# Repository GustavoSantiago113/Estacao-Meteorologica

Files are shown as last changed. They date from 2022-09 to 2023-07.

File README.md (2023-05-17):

# Weather Station

## List of Contents

1. [Objective](#objective)
2. [Weather Station working flow](#weather-station-working-flow)
3. [List of Materials](#list-of-materials)
4. [Circuit Board](#circuit-board)
5. [Algorithm](#algorithm)
6. [3D Files](#3d-files)
7. [Structure](#structure)
8. [Future works](#future-works)

---

## Objective
Develop a weather station to collect air temperature and humidity, luminosity, wind speed and precipitation in field using Arduino and sensors. It is energized with a solar panel and batteries. All data is saved in a microSD card along with the date and time.

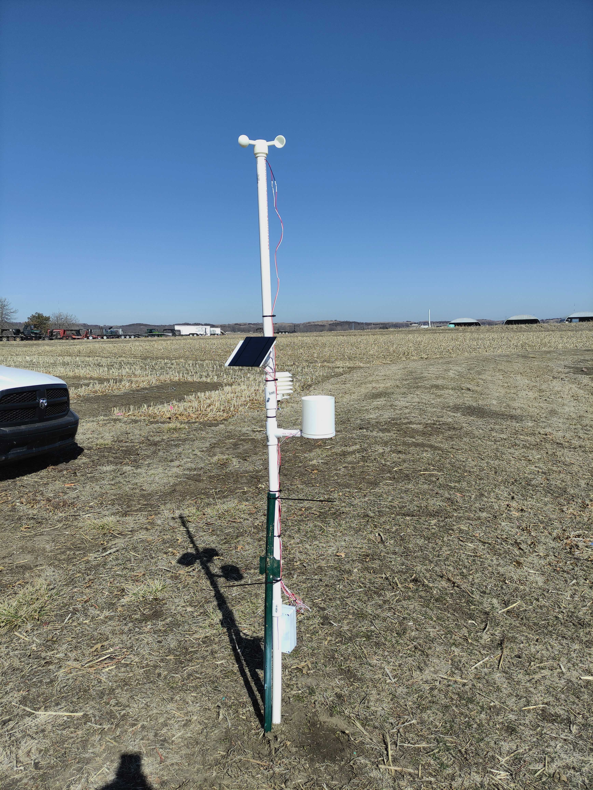
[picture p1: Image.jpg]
Weather Station build


---

## Weather Station working flow
Into a loop that repeats every 1 minute, the sensors get the data values and store into a .txt file. The .txt file is in the microSD card. Along with the sensors' reading data, the date and time is also sent to the .txt file.

The final .txt file is a line per reading with date, hour and sensors' data, all separated by commas.

---

## List of Materials

| Belongs to | Material | Amount |
|--- | --- | --- |
| Main Board | Arduino Uno | 1 |
| Main Board | microSD card module | 1 |
| Main Board | 32 GB microSD card | 1 |
| Main Board | RTC module DS3231 + battery | 1 |
| Main Board | Wires for connections | X |
| Main Board | Arduino enclosure | 1 |
| Rain Sensor | 3D structures in ABS | X |
| Rain Sensor | Rod of 3mm diameter and 30mm length (steel, aluminium...) possibly a little filed down to reduce to 2.95mm | 1 |
| Rain Sensor | Reed switch 1.8x7mm | 1 |
| Rain Sensor | 1k Ohm resistor | 1 |
| Rain Sensor | Round neodymium magnet 4x2mm | 1 |
| Rain Sensor | Bolts M3x6mm | 2 |
| Rain Sensor | Bolts or screws to fix the base on your support | 4 |
| Rain Sensor | Wires to connect to the reed switch | X |
| Rain Sensor | Glue to fix the magnet | A drop |
| Temperature & Humidity Sensor | AHT10 Sensor | 1 |
| Temperature & Humidity Sensor | 3D structures in ABS | X | 
| Temperature & Humidity Sensor | Bolts 10.5x0.5 cm and sow | 3 |
| Temperature & Humidity Sensor | Bolt to fix the sensor in place | 1 |
| Temperature & Humidity Sensor | Wires | X |
| Wind Sensor | Reed Switch 2x14mm | 1 |
| Wind Sensor | 1k Ohm resistor | 1 |
| Wind Sensor | Wires | X |
| Wind Sensor | 3D structures in ABS | X |
| Wind Sensor | Sealed bearing, 5 mm ID, 8mm OD, 2.5mm thick | 1 |
| Wind Sensor | Rod for the bearings 5mm OD | 1 |
| Wind Sensor | 1k ohm resistor | 1 |
| Structure | PVC pipe | 235cm x 4.83cm diameter |
| Structure | PVC pipe | 20cm x 3.34cm diameter |
| Structure | PVC pipe | 10cm x 2.66cm diameter |
| Structure | T junction / Reduction of 4.83cm to 3.34cm diameter | 2 |
| Structure | T junction / Reduction of 4.83cm to 2.66cm diameter | 1 |
| Energy | Charger Module | 1 |
| Energy | Diode 1n4007 | 1 |
| Energy | Panel with minimum 4Wp, 0.48A and 9V | 1 |
| Energy | Rechargeable battery of 0.3 Ah and 9V | 1 |
| Energy | Wires | X |
| Light Sensor | LDR 5mm | 1 |
| Light Sensor | 1k Ohm resistor | 1 |
| Light Sensor | Wires | X |

<br>

---

## Circuit Board
A circuit board were made to make everything more organized and avoid wrong connections and wires out of place. The .dxf file containing the circuit board's draw is in the folder Circuit_Board.

---

## Algorithm
The algorithm was made in C++ using Arduino IDE, since it is for Arduino. It is located in the Algorithm/Programa_o folder. The algorithm is structured as followed:
- Inclusion of libraries for SD card, RTC clock, temperature and humidity sensor;
- Declaration of variables for each sensor and module;
- Setup, that only runs once when the Arduino is restarted. On this function, i) the pin for the Pluviomether and Anemomether reed switchs' are declared; ii) initialize the microSD card; iii) the clock is initialized and adjusted only once; iV) the temperature and humidity sensor is initialized;
- Loop, that keep running. On this function, i) The super delay function is inserted to work every 5 minutes, ii) the Anemomether data (wind speed) is collected and adjusted, iii) the luminosity data is collected and adjusted, iv) temperature and humidity data is collected, v) the Pluviomether data is collected (rain) and adjusted, vi) Date and Time variables are collected and stored, vii) the .txt file in the microSD card is opened and all variables are stored into it, closing the .txt after that;
- Super delay function. It is created to take readings of rain and wind at everytime and just after a time, saves the data in the microSD card. To count the rain and wind, it verifies the state of the reed switch, and if it was changed, it is counted and the value changes.

---

## 3D Files
The main 3D files were all gotten at Thingiverse website, having different authors. The support 3D files were designed by the author in Fusion360 software.
### Anemomether
There are structures siliar to spoons that "collect" the wind, moving the axis attached to it. In the moving structure, there is a magnet that moves in the same speed as the spoons. A stopped structure holds the reed switch which captures the magnet movement and records how many times it passed through.

### Pluviomether
A funnel recalls the rain and send it directly to a bending tool that, when full, bends and throw the water away. As it bends, the magnet attached to it makes the reed switch records the movement and store how many time it bended (amount of rain).

### Temperature and humidity sensor protector
Just a structure to protect the sensor against the rain, wind and other environmental issues, in an attempt to reduce errors for the readings

---

## Structure
A PVC structure were built and stucked 50cm in the ground. As the image below shows, three Ts in 120 degrees between them are in the pipe to attach the sensor and solar panel structures'.
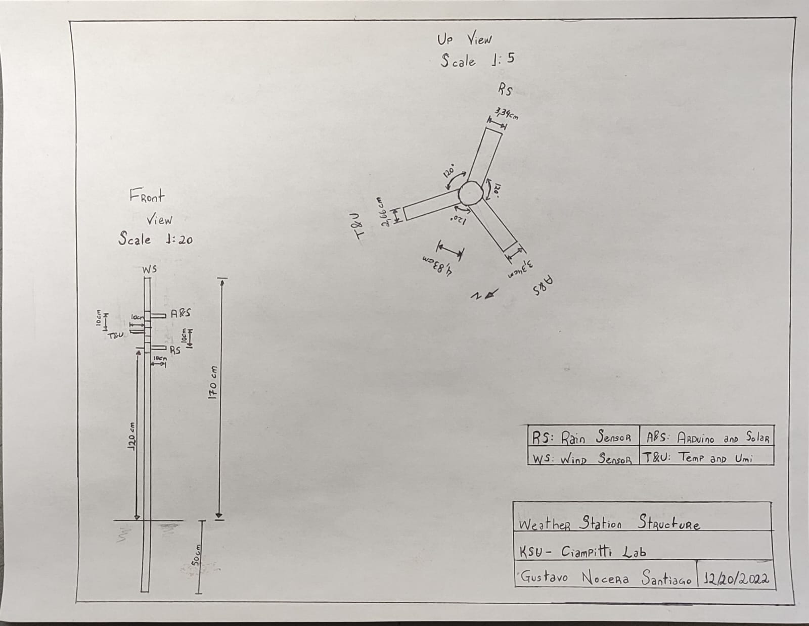
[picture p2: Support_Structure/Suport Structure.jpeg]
Structure


---

## Future works

The future work is to connect the weather station to the internet and upload the data to the cloud. Being the data in an online database, there is no need of removing and reading the microSD card. Also, spread weather stations over Kansas to obtain real time weather data of all the state. And lastly, Connect the database to a web application.

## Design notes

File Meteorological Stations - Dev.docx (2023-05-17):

Development of Meteorological Stations

Idea: Building stations to measure the most important agronomical variables and save information

Number of Stations: X

Variables required to measure: Temperature, Atmospheric pressure, wind speed, air humidity, luminosity, precipitation.

Places where will be the stations

- North Farm

Working alternatives:

- Batteries and Solar Pannel
- Electrical line using a 12/3.5 v charger
- Modern approach as shown in article: “Hybridized energy harvesting device based on high-performance triboelectric nanogenerator for smart agriculture applications"

Boards Alternatives

- Arduino UNO
- Arduino Nano
- NodeMCU
- Look at some boards with bluetooth/wifi

Structures

- 3D printed (Sensors and boards protections’);
- Commercial ones;
- Build in places that works with metal (Sustentation)

Inventory

- Arduino boards: 5
- Temperature/Humidity sensor: 1
- Pressure sensor: 0
- Batteries
- 2x 3.7V and 2000mAh
- 1x 3.7V and ? mAh
- 6x 1.2V and 1300mAh
- 1x 11.1 V
- 7x Batteries holders
- Solar Pannels: 5
- Cables
- 3x Arduino UNO – USB
- 29x Female-male pin
- 29x Female-male protected gathered in 3
- 29x Male protected-non protected gathered in 2
- 27x Female protected-male non protected gathered in 2
- 12x 9V battery clips
- Regulator charge: 16
- Arduino Clocks: 1
- Clock: 0
- Soil moisture sensors*: 1
- Air humidity sensor: 0
- Luminosity sensor
- 2x TSL2561
- 39 LDR
- Magnetic sensor (Reed Switch): 19
- Resistors: 25 of (470, 270, 33, 1k, 100k, 2.2k, 3.3k, 10k, 330, 100, 68, 150, 2k, 4.7k, 220 Ohm)
- Capacitor 100uF: 10
- Diodo IN4007: 50
- 1 Small protoboard
- 2 micro SD shield with 8GB microSD
- 1 SD shield without SD Card
- Water level sensor: 2
- Rain sensor: 2
- 3 Packs of heat shrink

References

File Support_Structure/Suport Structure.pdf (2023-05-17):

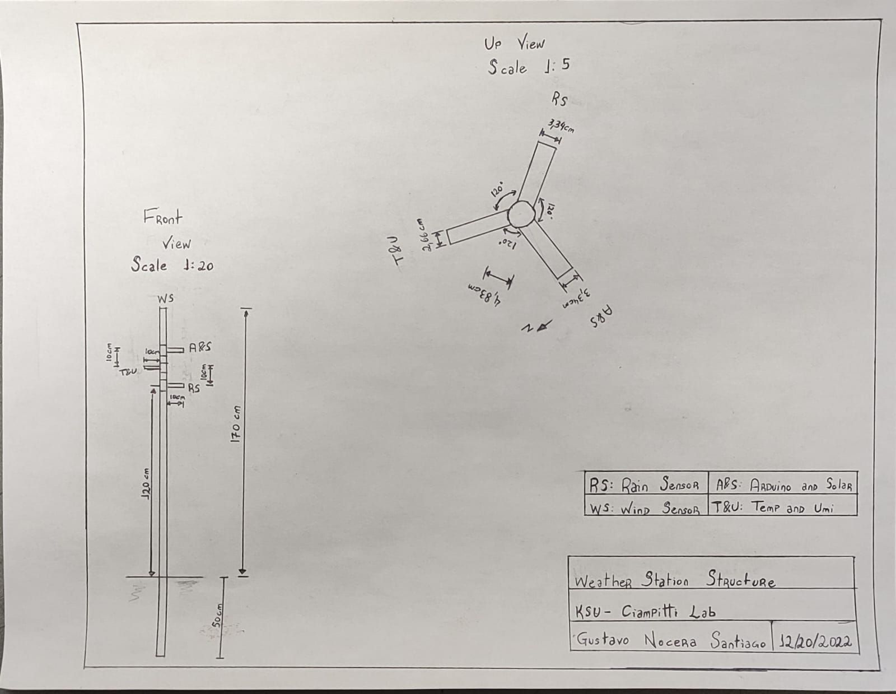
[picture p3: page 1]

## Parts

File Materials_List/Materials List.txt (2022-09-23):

1x AHT10;

2x Sensor magnético Reed Switch;

2x Resistor 1kΩ;

1x LDR 5 mm;

1x Resistor 10kΩ;

1x RTC DS3231 com bateria;

1X LCD1602 + I2C (LCM1602);

1X Módulo SD Card;

1x Arduino Nano;

1x Cartão SD;

1x Diodo 1n4007;

1x Capacitor de 100μF e 16 V;

1x Clip de bateria 9V;

1x Indicador de carga de bateria;

1x Bateria recarregável de 9 V e 450 mAh (mínimo);

1x Painel solar de 12 Wp (mínimo), 9 V e 2A ou 2x Painéis solares de 12Wp(mínimo), 9 V e 1A.

Cabos jumper macho-macho e macho-fêmea;

2x Ímãs pequenos;

Estrutura de suporte;

Placa de circuito;

Estruturas 3D (com rolamento e eixo para o anemômetro);

Cabo para passar a ligação ao Arduino;

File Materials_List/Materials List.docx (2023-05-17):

Main Board

1x Arduino Uno

1x SD card board for Arduino Uno + 32 GB SD card

Wires for connections

1x Clock module DS3231 + battery

1x Arduino enclosure

Rain Sensor

1x Rod of 3mm diameter and 30mm length (steel, aluminium...) possibly a little filed down to reduce to 2.95mm.

1x Reed switch 1.8x7mm

1x Round neodymium magnet 4x2mm

2x Bolts M3x6mm

4x Bolts or screws to fix the base on your support.

Wires, connector as you like to connect to the reed switch.

A drop of glue to fix the magnet.

3D structures printed in ABS

1x 1k ohm resistor

Temperature and Humidity Sensor

1x AHT10 Sensor

3D structures printed in ABS

3x Bolts 10.5x0.5 cm and sow

1x Bolt to fix the sensor in place

Wires

Wind Sensor

1x Reed Switch 2x14mm

Wires

3D structures printed in ABS

1x Sealed bearing, 5 mm ID, 8mm OD, 2.5mm thick

1x Rod for the bearings 5mm OD

1x 1k ohm resistor

Structure

235cm x 4.83cm diameter PVC pipe

3x T junction of 4.83cm diameter

2x reduction from 4.83cm to 3.34cm diameter

1x reduction from 4.83cm to 2.66cm diameter

20cm x 3.34cm diameter PVC pipe

10cm x 2.66cm diameter PVC pipe

Energy

1x Capacitor of 100uF and 16V

1x Diode 1n4007

1x Panel having minimum of 4 Wp and 0.48 and 9V

1x Rechargeable battery of 9.2 Ah and 9V (If use on winter)

1x Rechargeable battery of 8.2 Ah and 9V (If not using on winter)

Wires

Light

1x LDR 5mm

1x 1k ohm resistor

Wires

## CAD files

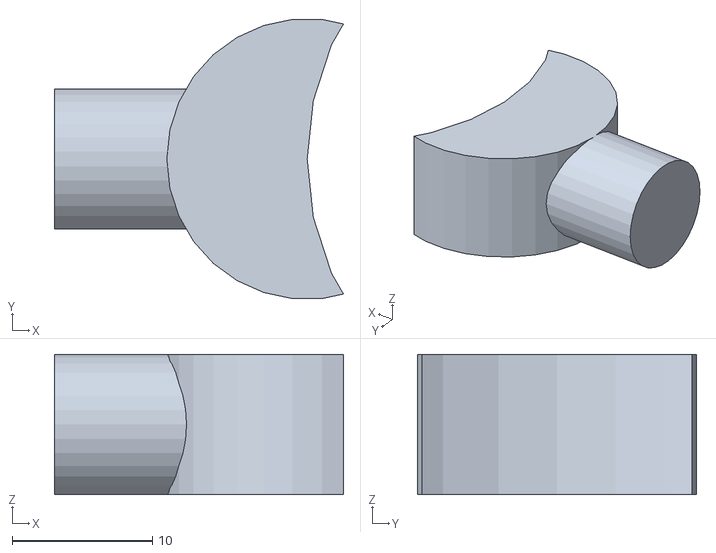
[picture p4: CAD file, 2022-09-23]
3D_Structure/Anemômetro/04Anem_bracket.stl
20.6 x 19.9 x 10.0

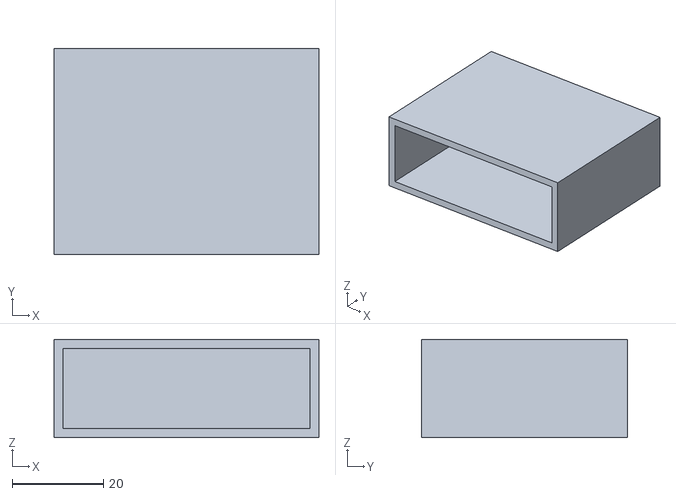
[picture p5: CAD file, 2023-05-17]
3D_Structure/Battery Holder.stl
58.0 x 45.0 x 21.5

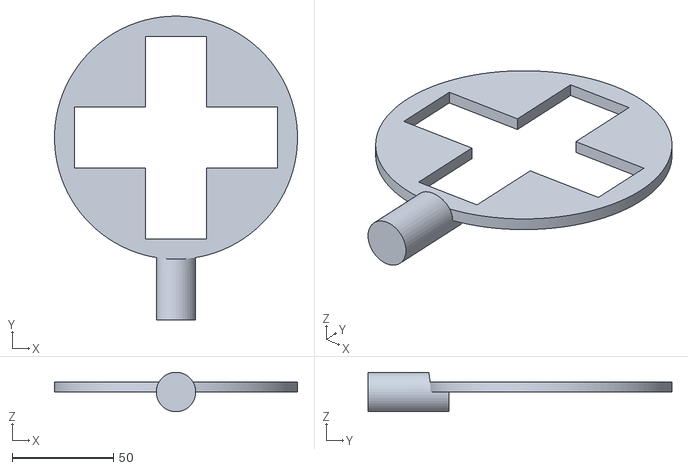
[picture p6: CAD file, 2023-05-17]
3D_Structure/Pluviômetro/Attachment to support.stl
120.0 x 150.0 x 19.5

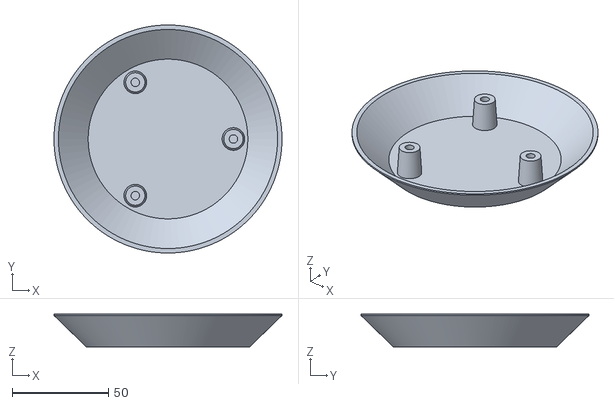
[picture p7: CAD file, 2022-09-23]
3D_Structure/Protetor temp e umi/Rad_Shd_Top_V1.stl
118.5 x 118.5 x 17.0

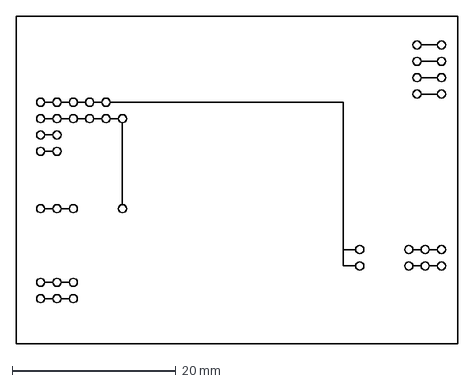
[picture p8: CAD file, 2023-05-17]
Circuit_Board/Circuit_Board.dxf
54.0 x 40.0 mm

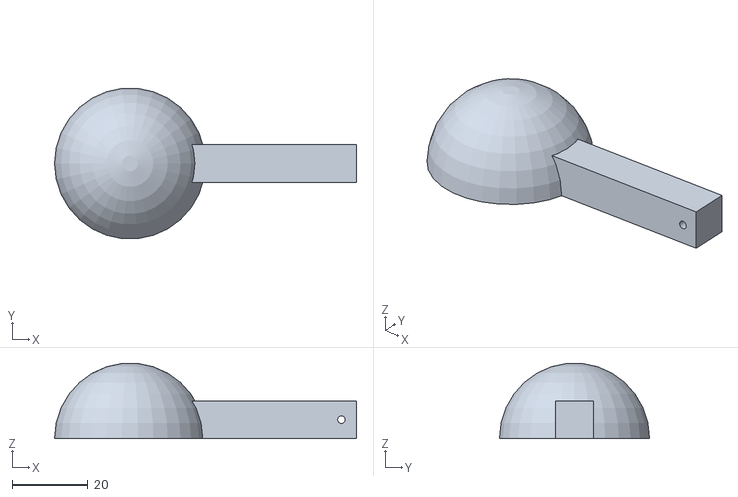
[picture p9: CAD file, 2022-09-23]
3D_Structure/Anemômetro/01Anem_Cup.stl
80.0 x 39.8 x 19.9

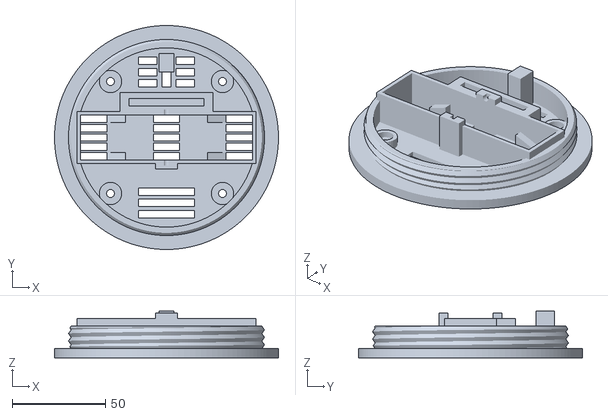
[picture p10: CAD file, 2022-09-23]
3D_Structure/Pluviômetro/Base.stl
120.0 x 120.0 x 25.0

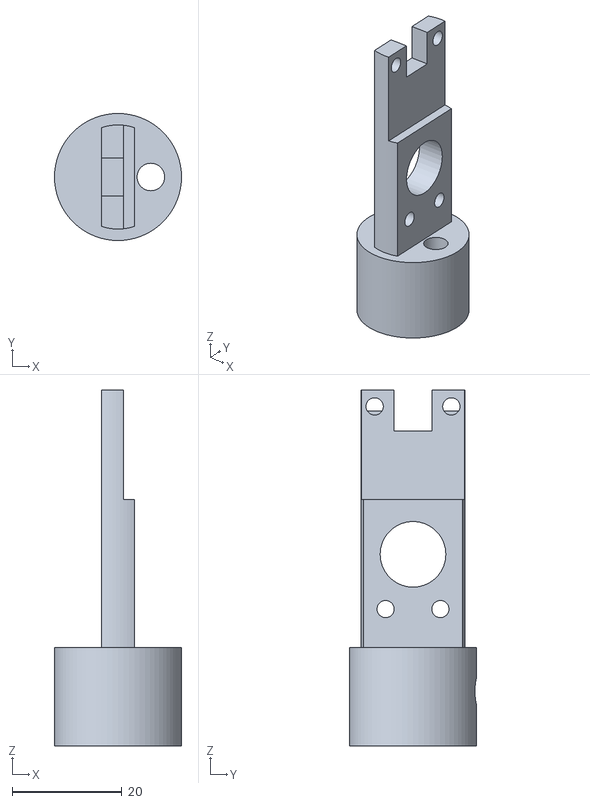
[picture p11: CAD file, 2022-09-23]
3D_Structure/Protetor temp e umi/SHT15_mount_V1.stl
23.2 x 23.2 x 65.0

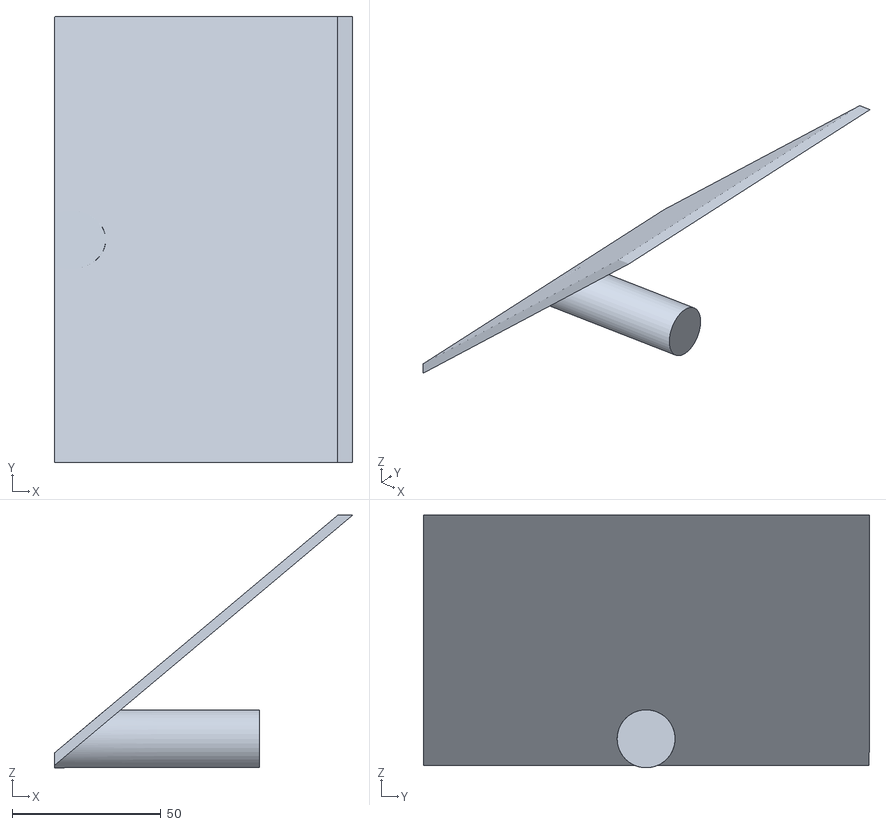
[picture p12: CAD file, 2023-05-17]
3D_Structure/Solar.stl
100.4 x 150.1 x 85.0

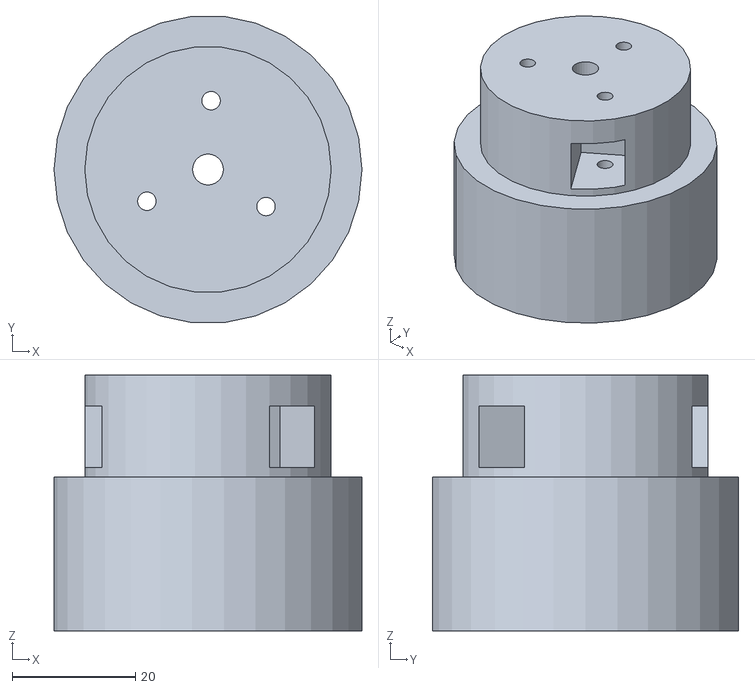
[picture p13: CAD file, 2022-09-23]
3D_Structure/Anemômetro/02Anem_center.stl
50.0 x 49.7 x 41.5

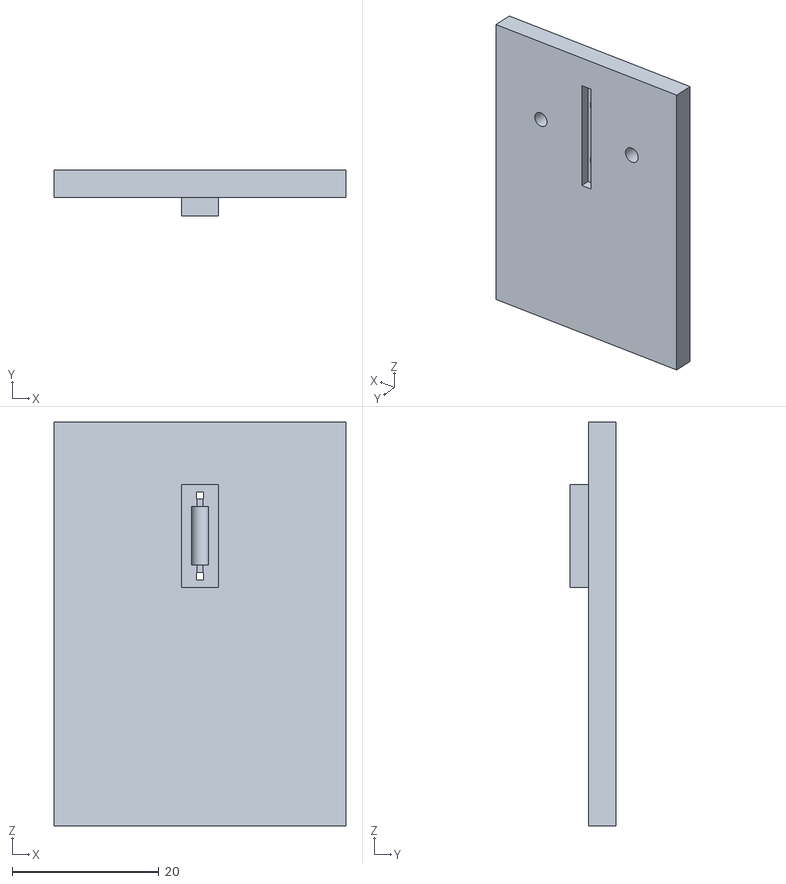
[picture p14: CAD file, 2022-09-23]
3D_Structure/Pluviômetro/Sensor.stl
39.8 x 6.25 x 55.0

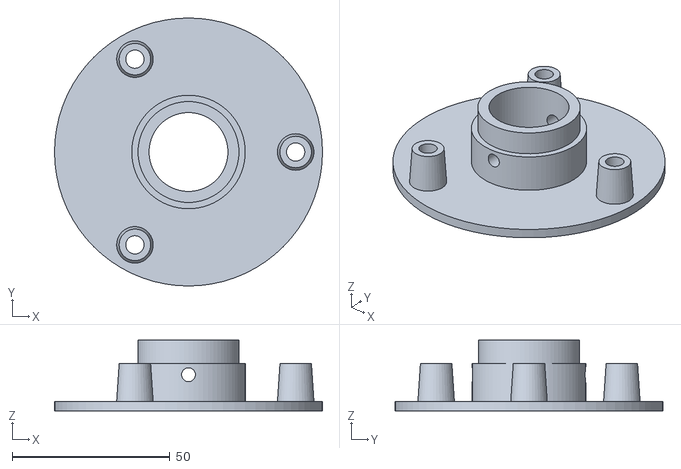
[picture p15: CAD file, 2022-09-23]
3D_Structure/Protetor temp e umi/Rad_Shd_Base_V1.stl
85.0 x 85.0 x 22.5

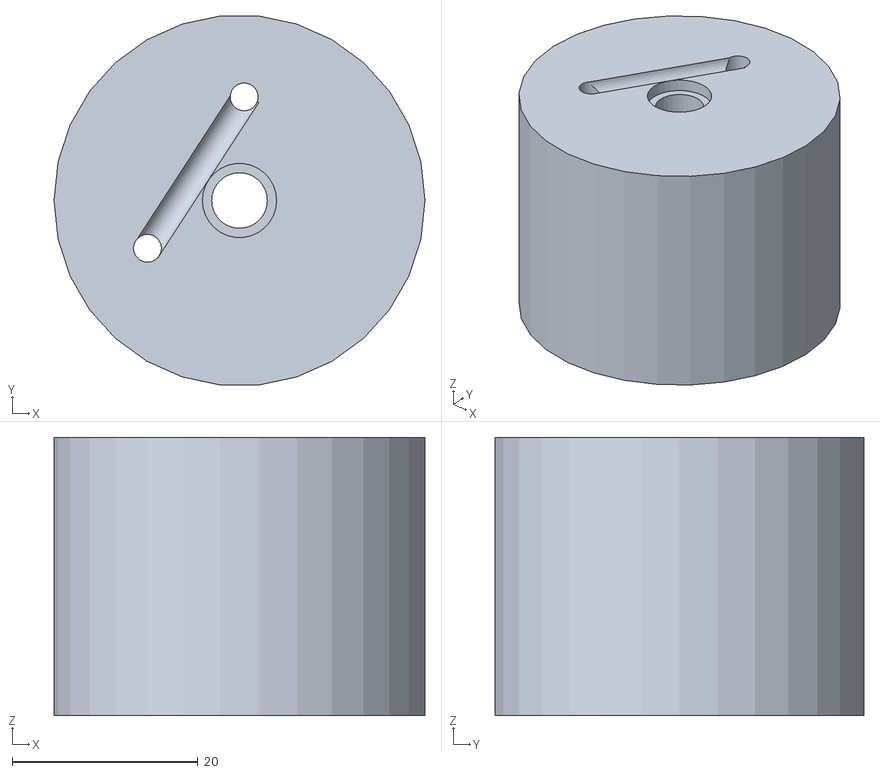
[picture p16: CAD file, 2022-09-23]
3D_Structure/Anemômetro/03Anem_Base.stl
40.0 x 39.8 x 30.0

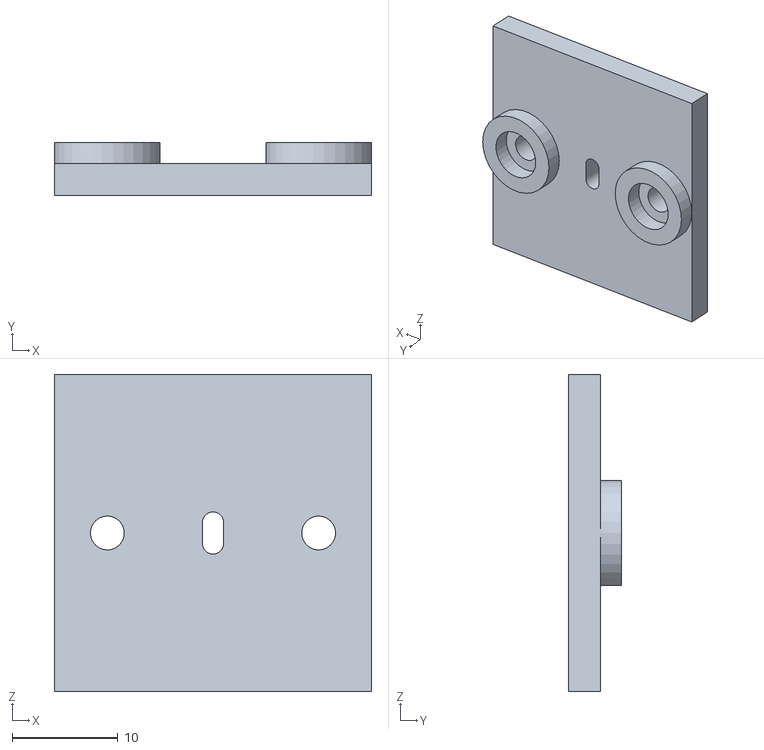
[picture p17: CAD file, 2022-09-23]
3D_Structure/Pluviômetro/Sensor_back.stl
30.0 x 5.00 x 30.0

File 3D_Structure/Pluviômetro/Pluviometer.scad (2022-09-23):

include <polyScrewThread_r1.scad>

full = true;
fnval = 120;



module cylinder_nut(df,hg,sth,clf,cod,crs){  
  hex_countersink_ends(sth/2,cod,clf,crs,hg);
  screw_thread(cod,sth,clf,hg,crs,-2);
}

module triangleR(a, b, h, c){
  linear_extrude(height = h, center = c, convexity = 10)
  resize([a, b])
  polygon([[0,0], [1,0], [0,1]], paths=[[0,1,2]]);
}

module triangleRa(a, angle, h, c){
  rotate([90, 0, 0])
  linear_extrude(height = h, center = c, convexity = 10)
  resize([a, a*tan(angle)])
  polygon([[0,0], [1,0], [0,1]], paths=[[0,1,2]]);
}

module triangleI(x, y, z, c){
  rotate([90, 0, 0])
  linear_extrude(height = y, center = c, convexity = 10)
  resize([x, z])
  polygon([[-1,0], [1,0], [0,1]], paths=[[0,1,2]]);
}


module bucket2(){
  difference(){
    union(){
      difference(){
        triangleI(70, 20, 25, true);
        
        translate([-70/4-1/2, 0, (25+2)/2]) cube([70/2, 20-4, 25-2], center = true);
        translate([70/4+1/2, 0, (25+2)/2]) cube([70/2, 20-4, 25-2], center = true);
      }
      
      triangleI(20, 20, 15, true);
    }
    
    translate([0, 0, 3]) rotate([90, 0, 0]) cylinder(d=3.25, h=20, center=true, $fn=30);
  }
  
  //magnet
  translate([0, 10+2/2, 21])
  rotate([90, 0, 0])
  difference(){
    cylinder(d=6.25, h=2, center=true, $fn=30);
    cylinder(d=4.25, h=2, center=true, $fn=30);
  }  
}

module bucket(){
  difference(){
    union(){
      difference(){
        triangleI(70, 20, 25, true);
        
        translate([-70/4-1/2, 0, (25+1)/2]) cube([70/2, 20-2, 25-1], center = true);
        translate([70/4+1/2, 0, (25+1)/2]) cube([70/2, 20-2, 25-1], center = true);
      }
      
      triangleI(25, 20, 15, true);
    }
    
    translate([0, 0, 3]) rotate([90, 0, 0]) cylinder(d=3.25, h=20, center=true, $fn=30);
  }
  
  //magnet
  translate([0, 10+2/2, 21])
  rotate([90, 0, 0])
  difference(){
    cylinder(d=6.25, h=2, center=true, $fn=30);
    cylinder(d=4.25, h=2, center=true, $fn=30);
  }  
}

module base(){
  translate([0, 0, -5/2])
  difference(){
    cylinder(d=120, h=5, center=true, $fn=fnval);
    
    //water holes
    for(dy = [-2:1:2], dx = [-1, 0, 1]){
      translate([-39*dx, 5*dy, 0]) cube([14, 4, 5], center = true);
    }  

    for(dy = [-1:1:1]){
      translate([0, 6*dy-35, 0]) cube([30, 4, 5], center = true);
    }    
    
    for(dy = [-1:1:1], dx = [-1, 1]){
      translate([10*dx, 6*dy+35, 0]) cube([10, 4, 5], center = true);
    }   
    
    //screw holes
    for(dx = [-1,1], dy = [-1, 1]){
      translate([30*dx, 30*dy, 0]) cylinder(d=4.25, h=5, center=true, $fn=30);
    }
    
    //cable hole
    translate([0, 31, 0]) cube([5, 8, 5], center = true);
  }
  
  //screw holes
  for(dx = [-1,1], dy = [-1, 1]){
    translate([30*dx, 30*dy, 0]) 
    difference(){
      cylinder(d=12, h=5, center=false, $fn=30);
      cylinder(d=4.25, h=5, center=false, $fn=30);
      translate([0, 0, 5-3]) cylinder(d=8, h=3, center=false, $fn=30);
    }
  }
  
  //cable holder
  translate([0, 31+8/2+10/2, 20/2]) cube([8, 10, 20], center = true);
  
  //border
  translate([0, 0, 16/2])
  difference(){
    cube([92+2*2, 24+2*2, 16], center = true);
    cube([92, 24, 16], center = true);
  }
   
  
  //holder
  difference(){
    translate([0, 0, 18/2+1/2]) cube([12, 20+2*2+2*5, 19], center = true);
    
    translate([0, 0, 18/2]) cube([12, 20+2*2, 20], center = true);
    translate([0, 0, 18]) rotate([90, 0, 0]) cylinder(d=3.25, h=20+2*2+2*3, center=true, $fn=30);
  }
  
  //stop
  difference(){
      for(dx = [-1, 1]) {
        translate([22*dx, 0, 3]) scale([dx, 1, 1]) {
          translate([10/2, 0, -3/2]) cube([10, 24, 3], center = true);
          triangleRa(10, 20, 24, true);
        }
      }
      translate([0, 0, 10/2]) cube([70, 20-2*2, 10], center = true);
  }
  
  //pcb holder  
  translate([0, 19, 16/2])
  difference(){
    cube([50, 10, 16], center = true);
    cube([40, 4, 16], center = true);
  }
  
  
  //thread  
  if(full){
    difference(){
      translate([0, 0, 0]) screw_thread(105, 4, 55, 12, PI/2, 2);
      cylinder(d=96, h=14, center=false, $fn=fnval);
    }
  }
  else{
    difference(){
      cylinder(d=105, h=14, center=false, $fn=fnval);
      cylinder(d=96, h=14, center=false, $fn=fnval);
    }
  }
    
  
}

module funnel(){
  
  difference(){
    union(){
      translate([0, 0, 120])
      mirror([0, 0, 1])
      rotate_extrude(angle = 360, convexity = 2, $fn=fnval)
      difference(){
        resize([10*sqrt(100/PI)+2, 70+2])  polygon([[0,0], [1,0], [0,1]], paths=[[0,1,2]]);
        resize([10*sqrt(100/PI), 70])  polygon([[0,0], [1,0], [0,1]], paths=[[0,1,2]]);
      }
            
      difference(){
        cylinder(r=10*sqrt(100/PI)+2, h=120, center=false, $fn=fnval);
        cylinder(r=10*sqrt(100/PI), h=120, center=false, $fn=fnval);
      }
      
      
      translate([0, 0, 120-70-10+2.5]) cylinder(d=7, h=10, center=false, $fn=30);
    }
    translate([0, 0, 120-70-10+2.5]) cylinder(d=5, h=10, center=false, $fn=30);
  }
  
  difference(){
    translate([0, 0, 14/2]) cylinder(r=10*sqrt(100/PI), h=14, center=true, $fn=fnval);
    if(full){
      cylinder_nut(100, 14, 4, 55, 105.5, 0.5);
    }
    else{
      translate([0, 0, 14/2]) cylinder(d=105.5, h=14, center=true, $fn=fnval);
    }
  }
  
  translate([0, 0, 14+5/2]) 
  difference(){
    cylinder(r=10*sqrt(100/PI), h=5, center=true, $fn=fnval);
    cylinder(r2=10*sqrt(100/PI), r1=105.5/2, h=5, center=true, $fn=fnval);
  }
  
  
}

module sensor(){
    difference(){
        union(){
            translate([0, -0.25/2, 0]) cube([40-0.25, 4-0.25, 55], center = true);
            
            translate([0, -3, 12])
            difference(){
                cube([5, 3, 14], center = true);
                translate([0, -3/2+2.25/2, 0]) cylinder(d=2.25, h=8, center=true, $fn=30);
                translate([0, -3/2+2.25/4, 0]) cube([2.25, 2.25/2, 8], center = true);
                translate([0, -3/2+2.25/4, 0]) cube([0.75, 2.25/2, 12], center = true);
            }
            
        }
                
        translate([0, -1, 12+6-0.5]) cube([1, 8, 1], center = true);
        translate([0, -1, 12-6+0.5]) cube([1, 8, 1], center = true);
        
        translate([0, 1.75/2, 12]) cube([2, 1.75, 20], center = true);
        
        for(dx = [-1, 1]) 
        translate([-10*dx, (3.75-3)/2, 12]) rotate([90, 0, 0]) cylinder(d=2.7, h=3, center=true, $fn=30);
     }
}

module sensor_back(){
    difference(){
        translate([0, 0, 0]) cube([30, 3, 30], center = true);
    
        for(dx = [-1, 1]) 
            translate([-10*dx, 0, 0]) rotate([90, 0, 0]) cylinder(d=3.2, h=5, center=true, $fn=30);

        hull(){
            translate([0, 0, 1]) rotate([90, 0, 0]) cylinder(d=2, h=5, center=true, $fn=30);
            translate([0, 0, -1]) rotate([90, 0, 0]) cylinder(d=2, h=5, center=true, $fn=30);
        }
    }
    
    for(dx = [-1, 1]) 
        translate([-10*dx, (3+2)/2, 0]) rotate([90, 0, 0])
            difference(){
               cylinder(d=10, h=2, center=true, $fn=30);
               cylinder(d=6, h=2, center=true, $fn=30);
            }
    
}

module bending_tool(){
    difference(){
        cube([11, 5, 5], center = true);
        translate([0, 0, 2]) cube([11, 1, 1], center = true);
        translate([0, 0, 2]) cube([8, 2, 2], center = true);
    }
}

module assembled(){
    translate([0, 0, -18])base();
    rotate([0, 0, 0]) translate([0, 0, -3]) bucket();
    translate([0, 19, 55/2-18]) sensor();
    translate([0, 24, 55/2-18+12]) sensor_back();
    translate([0, 0, -18]) funnel();
}

module exploded(){
    translate([0, 0, -18])base();
    rotate([0, 0, 0]) translate([0, 0, 20]) bucket();
    translate([0, 19, 30]) sensor();
    translate([0, 30, 42]) sensor_back();
    translate([0, 0, 70]) funnel();
}

//assembled();

exploded();

//bending_tool();

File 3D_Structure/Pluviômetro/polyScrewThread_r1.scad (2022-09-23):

/*
 *    polyScrewThread_r1.scad    by aubenc @ Thingiverse
 *
 * This script contains the library modules that can be used to generate
 * threaded rods, screws and nuts.
 *
 * http://www.thingiverse.com/thing:8796
 *
 * CC Public Domain
 */

module screw_thread(od,st,lf0,lt,rs,cs)
{
    or=od/2;
    ir=or-st/2*cos(lf0)/sin(lf0);
    pf=2*PI*or;
    sn=floor(pf/rs);
    lfxy=360/sn;
    ttn=round(lt/st+1);
    zt=st/sn;

    intersection()
    {
        if (cs >= -1)
        {
           thread_shape(cs,lt,or,ir,sn,st);
        }

        full_thread(ttn,st,sn,zt,lfxy,or,ir);
    }
}

module hex_nut(df,hg,sth,clf,cod,crs)
{

    difference()
    {
        hex_head(hg,df);

        hex_countersink_ends(sth/2,cod,clf,crs,hg);

        screw_thread(cod,sth,clf,hg,crs,-2);
    }
}


module hex_screw(od,st,lf0,lt,rs,cs,df,hg,ntl,ntd)
{
    ntr=od/2-(st/2)*cos(lf0)/sin(lf0);

    union()
    {
        hex_head(hg,df);

        translate([0,0,hg])
        if ( ntl == 0 )
        {
            cylinder(h=0.01, r=ntr, center=true);
        }
        else
        {
            if ( ntd == -1 )
            {
                cylinder(h=ntl+0.01, r=ntr, $fn=floor(od*PI/rs), center=false);
            }
            else if ( ntd == 0 )
            {
                union()
                {
                    cylinder(h=ntl-st/2,
                             r=od/2, $fn=floor(od*PI/rs), center=false);

                    translate([0,0,ntl-st/2])
                    cylinder(h=st/2,
                             r1=od/2, r2=ntr, 
                             $fn=floor(od*PI/rs), center=false);
                }
            }
            else
            {
                cylinder(h=ntl, r=ntd/2, $fn=ntd*PI/rs, center=false);
            }
        }

        translate([0,0,ntl+hg]) screw_thread(od,st,lf0,lt,rs,cs);
    }
}

module hex_screw_0(od,st,lf0,lt,rs,cs,df,hg,ntl,ntd)
{
    ntr=od/2-(st/2)*cos(lf0)/sin(lf0);

    union()
    {
        hex_head_0(hg,df);

        translate([0,0,hg])
        if ( ntl == 0 )
        {
            cylinder(h=0.01, r=ntr, center=true);
        }
        else
        {
            if ( ntd == -1 )
            {
                cylinder(h=ntl+0.01, r=ntr, $fn=floor(od*PI/rs), center=false);
            }
            else if ( ntd == 0 )
            {
                union()
                {
                    cylinder(h=ntl-st/2,
                             r=od/2, $fn=floor(od*PI/rs), center=false);

                    translate([0,0,ntl-st/2])
                    cylinder(h=st/2,
                             r1=od/2, r2=ntr, 
                             $fn=floor(od*PI/rs), center=false);
                }
            }
            else
            {
                cylinder(h=ntl, r=ntd/2, $fn=ntd*PI/rs, center=false);
            }
        }

        translate([0,0,ntl+hg]) screw_thread(od,st,lf0,lt,rs,cs);
    }
}

module thread_shape(cs,lt,or,ir,sn,st)
{
    if ( cs == 0 )
    {
        cylinder(h=lt, r=or, $fn=sn, center=false);
    }
    else
    {
        union()
        {
            translate([0,0,st/2])
              cylinder(h=lt-st+0.005, r=or, $fn=sn, center=false);

            if ( cs == -1 || cs == 2 )
            {
                cylinder(h=st/2, r1=ir, r2=or, $fn=sn, center=false);
            }
            else
            {
                cylinder(h=st/2, r=or, $fn=sn, center=false);
            }

            translate([0,0,lt-st/2])
            if ( cs == 1 || cs == 2 )
            {
                  cylinder(h=st/2, r1=or, r2=ir, $fn=sn, center=false);
            }
            else
            {
                cylinder(h=st/2, r=or, $fn=sn, center=false);
            }
        }
    }
}

module full_thread(ttn,st,sn,zt,lfxy,or,ir)
{
  if(ir >= 0.2)
  {
    for(i=[0:ttn-1])
    {
        for(j=[0:sn-1])
        let( pt = [	[0,                  0,                  i*st-st            ],
                        [ir*cos(j*lfxy),     ir*sin(j*lfxy),     i*st+j*zt-st       ],
                        [ir*cos((j+1)*lfxy), ir*sin((j+1)*lfxy), i*st+(j+1)*zt-st   ],
								[0,0,i*st],
                        [or*cos(j*lfxy),     or*sin(j*lfxy),     i*st+j*zt-st/2     ],
                        [or*cos((j+1)*lfxy), or*sin((j+1)*lfxy), i*st+(j+1)*zt-st/2 ],
                        [ir*cos(j*lfxy),     ir*sin(j*lfxy),     i*st+j*zt          ],
                        [ir*cos((j+1)*lfxy), ir*sin((j+1)*lfxy), i*st+(j+1)*zt      ],
                        [0,                  0,                  i*st+st            ]	])
        {
            polyhedron(points=pt,
              		  faces=[	[1,0,3],[1,3,6],[6,3,8],[1,6,4],
											[0,1,2],[1,4,2],[2,4,5],[5,4,6],[5,6,7],[7,6,8],
											[7,8,3],[0,2,3],[3,2,7],[7,2,5]	]);
        }
    }
  }
  else
  {
    echo("Step Degrees too agresive, the thread will not be made!!");
    echo("Try to increase de value for the degrees and/or...");
    echo(" decrease the pitch value and/or...");
    echo(" increase the outer diameter value.");
  }
}

module hex_head(hg,df)
{
	rd0=df/2/sin(60);
	x0=0;	x1=df/2;	x2=x1+hg/2;
	y0=0;	y1=hg/2;	y2=hg;

	intersection()
	{
	   cylinder(h=hg, r=rd0, $fn=6, center=false);

		rotate_extrude(convexity=10, $fn=6*round(df*PI/6/0.5))
		polygon([ [x0,y0],[x1,y0],[x2,y1],[x1,y2],[x0,y2] ]);
	}
}

module hex_head_0(hg,df)
{
    cylinder(h=hg, r=df/2/sin(60), $fn=6, center=false);
}

module hex_countersink_ends(chg,cod,clf,crs,hg)
{
    translate([0,0,-0.1])
    cylinder(h=chg+0.01, 
             r1=cod/2, 
             r2=cod/2-(chg+0.1)*cos(clf)/sin(clf),
             $fn=floor(cod*PI/crs), center=false);

    translate([0,0,hg-chg+0.1])
    cylinder(h=chg+0.01, 
             r1=cod/2-(chg+0.1)*cos(clf)/sin(clf),
             r2=cod/2, 
             $fn=floor(cod*PI/crs), center=false);
}

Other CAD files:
3D_Structure/Protetor temp e umi/Rad_Shd_Fin_V1.stl
3D_Structure/Pluviômetro/Bending_tool.stl
3D_Structure/Protetor temp e umi/Rad_Shd_Horz_mount_V1.stl
3D_Structure/Pluviômetro/Bucket.stl

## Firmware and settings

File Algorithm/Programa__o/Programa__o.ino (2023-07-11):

// Author: Gustavo Nocera Santiago

// Including Libraries
#include <AHT10.h>
#include <Wire.h>
#include <SD.h>
#include <SPI.h>
#include <RTClib.h>

// Anemomether variables
const int REED = 3;
int val = 0;
int old_val = 0;
int REEDCOUNT = 0;
const float pi = 3.14159265;
float radius = 0.065;
float windspeed = 0;

// Temp and Humi Class
AHT10Class AHT10;
float temp;
float umi;

// SD Card Variables
File myFile;
const int pinCS = 10;

// Luminosity variables
#define LDR A0
int light;
int energy;

// Clock class
RTC_DS3231 rtc;

// Pluviomether variables
const int REEDR = 2;
int valR = 0;
int old_valR = 0;
int REEDCOUNTR = 0;
float rain = 0.00;

void setup(){
  
  Serial.begin(9600);
  
  // Pluviomether
  pinMode(REEDR, INPUT_PULLUP);

  // Anemomether
  pinMode(REED, INPUT_PULLUP);

  // SD Card
  pinMode(pinCS, OUTPUT);
  if (!SD.begin(8)) {
    Serial.println("Card failed, or not present");
    return;
  }
  Serial.println("card initialized.");

  // Clock
  if (! rtc.begin())
  {
    Serial.println("Módulo RTC no encontrado!");
    while(1);
    
  }
  
  //rtc.adjust(DateTime(F(__DATE__), F(__TIME__))); //Upload code once with this line uncommented so the clock is adjusted, then coment this line and upload again
  
  // Temp and Humi
  Wire.begin();

  if(AHT10.begin(eAHT10Address_Low)){
    Serial.println("Init AHT10 Success!");
  } 
  else{
    Serial.println("Init AHT10 Failed!");
  }
  
}

void loop(){
  
  if (analogRead(LDR > 700)){
    superDelay(3600000);
    // Anemomether
    windspeed = 2 * pi * radius * (REEDCOUNT / (60 * 60));
    readAndSave();
  }
  else{
    superDelay(7200000);
    // Anemomether
    windspeed = 2 * pi * radius * (REEDCOUNT / (60 * 120));
    readAndSave();
  }

}

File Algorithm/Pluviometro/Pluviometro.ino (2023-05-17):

#include <Wire.h>

// Constants:
const int REEDR = 2; //Rain "sensor" pin

// Variables:
int valR = 0;
int old_valR = 0;
int REEDCOUNTR = 0;
float rain = 0.00;

void setup()
{
  
  Serial.begin(9600); //Initialize serial comunication:
  
  pinMode (REEDR, INPUT_PULLUP); //Initialize switch pin as input

}
 
void loop() 
{

  superDelay(30000);

  valR = digitalRead(REEDR);      // Read Reed Switch status
  String dataString = "";

  rain = REEDCOUNTR / 11.00;      //Calculates rain value (Must be calibrated)

  //Converting and gathering data to be saved
  dataString += String("Counts: ");
  dataString += String(REEDCOUNTR);
  dataString += String(", ");
  dataString += String("Rain: ");
  dataString += String(rain);
  dataString += String("mm");

  Serial.println(dataString);

}

// Function to make anemomether works while other processes are happening
void superDelay(unsigned long tempoDeEspera) 
{
  unsigned long inicio = millis(); 
  while (millis() - inicio < tempoDeEspera) 
  { 

    // Rain
    valR = digitalRead(REEDR);
    
    if ((valR == LOW) && (old_valR == HIGH)) {
      delay(100);
      REEDCOUNTR = REEDCOUNTR + 1;
      old_valR = valR;
    }
    else {
      old_valR = valR;
    }
    
  }
}

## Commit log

2022-12-01 Anemometer and Power Supply
    [Power_Supply_Sizing.xlsx]
2023-03-10 Some changes
    [Attachment to support.stl, PCI.dwg, Power_Supply_Sizing.xlsx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]
2023-04-14 End of Version1
    [Battery Holder.stl, Circuit_Board.dxf]
2023-05-15 Battery charger added
    [Power_Supply_Sizing.xlsx]
